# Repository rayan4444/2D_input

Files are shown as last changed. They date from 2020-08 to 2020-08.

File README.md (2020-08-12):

# 2D Input on any surface

Eagle files Repository for 2D input project

## Modular version
Based on ESP32 to test different hardware configurations. One PCB design that can be snapped to separate core and peripheral modules. Test code available.

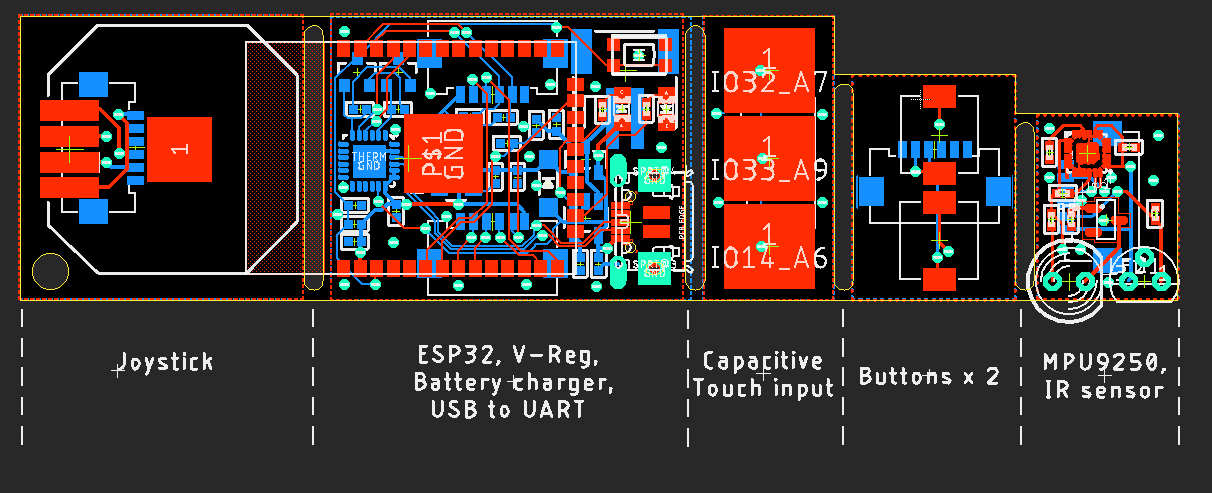
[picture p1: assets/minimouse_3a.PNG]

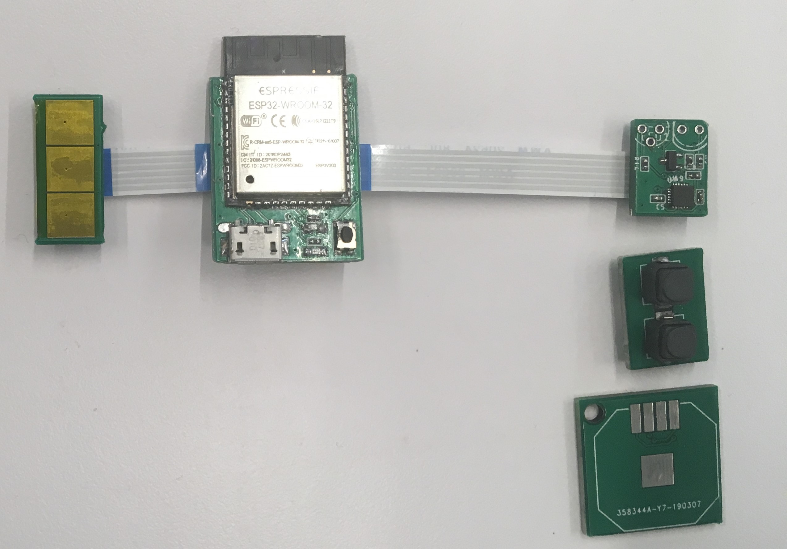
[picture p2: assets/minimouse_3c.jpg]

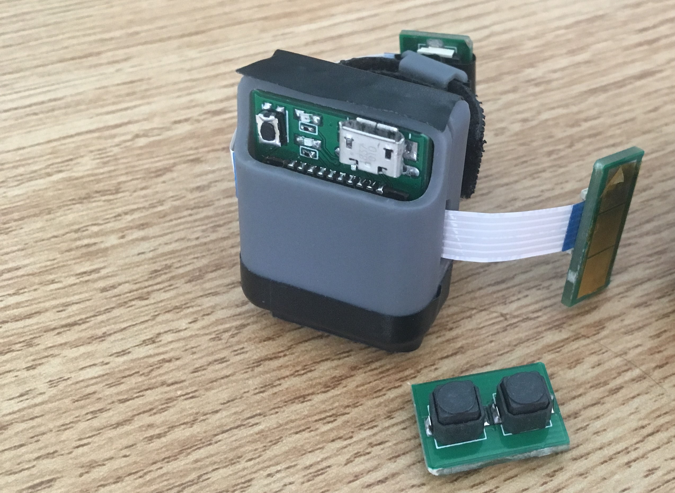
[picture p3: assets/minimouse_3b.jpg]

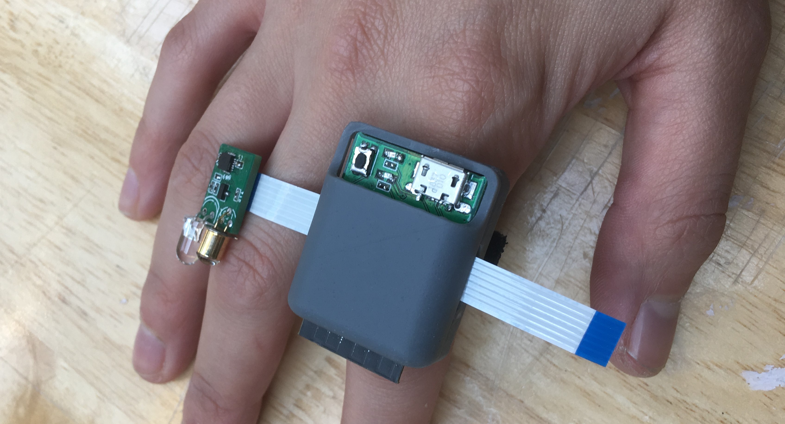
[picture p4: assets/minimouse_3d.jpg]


## Downsized version
Based on NRF52 as a first step to real manufacturing size. Firmware not available

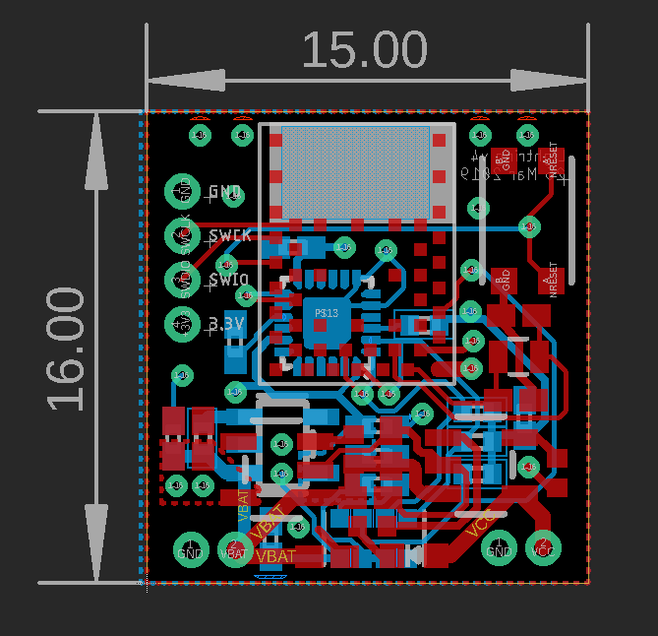
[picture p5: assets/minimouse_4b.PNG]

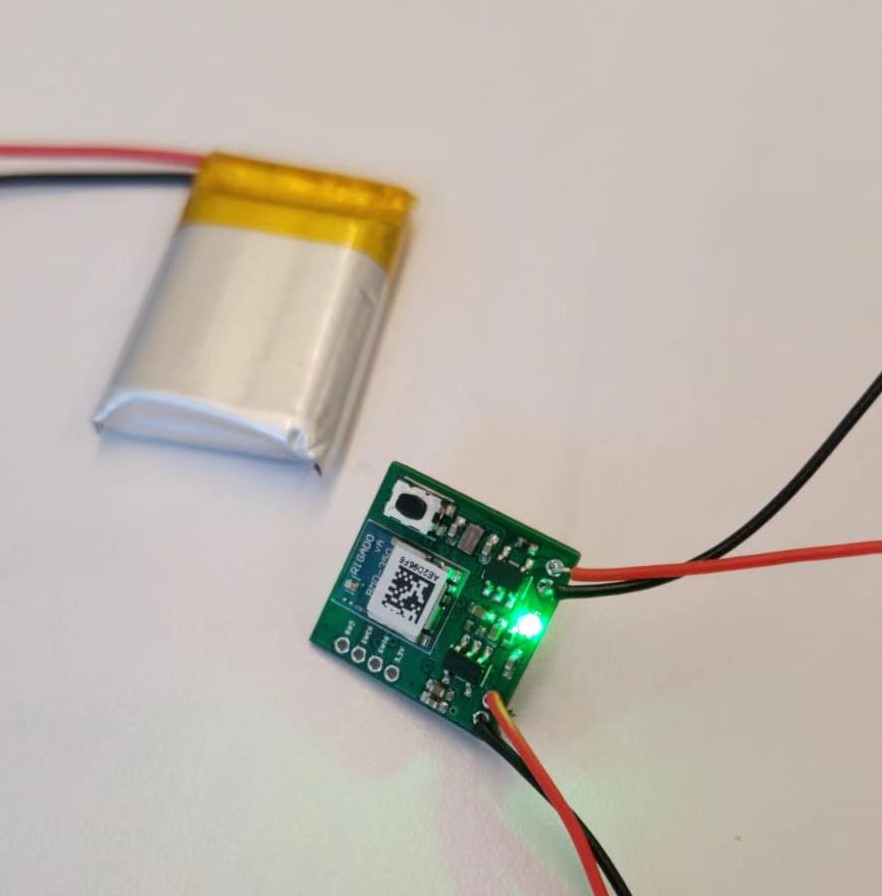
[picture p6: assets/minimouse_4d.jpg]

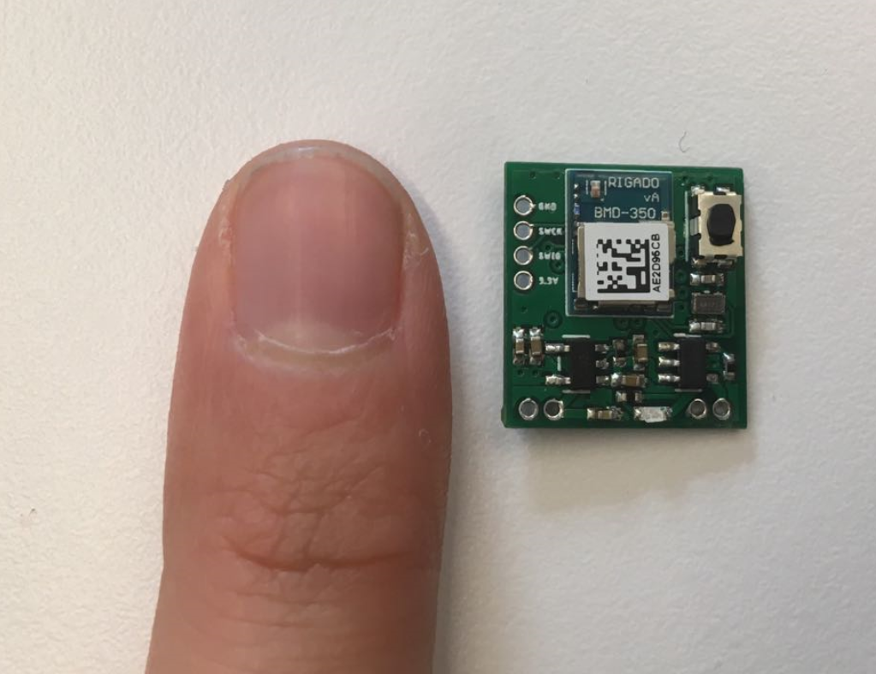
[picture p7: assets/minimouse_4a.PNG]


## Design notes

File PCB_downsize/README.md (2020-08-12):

# 2D Input on any surface - Downsized PCB

## Features
* NRF52 (BMD350 module)
* SWD Programming & debugging port
* 1S Li-Po charger
* 3.3V & 1.8V LDO
* MPU9250 IMU
* VCNL36687S Proximity sensor

## Hardware connections

|Signal|Pin|Note|
|:---:|:---:|:---:|
|RESET|21||
|INT_IMU|17||
|INT_IR|30||
|SDA|6||
|SCL|8||

## Debugging notes
* VCNL36687S soldered at 90 deg: one side pins soldered, other side using rework wire
* Add connector to external button in next version

## Programming
* Didn't get permission to share firmware
* [NRF52 dev with visual studio code](https://github.com/rayan4444/vs_code_setup_tutorials/tree/master/NRF52)

## Datasheets
* [BMD350](https://www.u-blox.com/sites/default/files/BMD-350_DataSheet_%28UBX-19033354%29.pdf)
* [MPU9250](https://invensense.tdk.com/wp-content/uploads/2015/02/PS-MPU-9250A-01-v1.1.pdf)
* [VCNL36687S](https://www.vishay.com/docs/84907/vcnl36687s.pdf)

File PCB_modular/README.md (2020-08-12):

# 2D Input on any surface - Modular PCB

## Features
Modular version - Core
* ESP32-WROOM32 Module
* CP2104 USB-UART bridge
* 1S Li-Po charger
* 3.3V LDO
* 2x FPC breakout connectors

Modular version - Peripherals
* MPU9250 IMU
* Custom narrow angle IR sensor ( & )
* 2x buttons
* Capacitive touch sensor board (3 positions)
* Joystick

## Hardware connections

|Signal| Arduino Pin|Note|
|:---:|:---:|:---:|
|RXD0|RXD0|Programming|
|TXD0|TXD0|Programming|
|IMU_SDA|23|
|IMU_SCL|22|
|BUTTON 1 or CAP_TOUCH_1|14, A6||
|BUTTON 2|15||
|CAP_TOUCH_2 or JOY_X|33, A9||
|CAP_TOUCH_3 or JOY_Y|32, A7||
|LED|13||
|IR_LED|12||
|IR_SENSOR_OUT|34, A2|Analog|

## Programming
Follow normal Arduino for ESP32 instructions. Select "Adafruit feather" as Board in Arduino IDE to program.

## Errata
* MPU9250 is discontinued - don't use it for any new designs
* Problem: cannot connect to the MCU to flash it.   
    * Solution: Missing trace on GPIO0 line that connects to the auto-reset circuit. Used a rework wire as a temporary fix.

## References & tutorials
* [MPU4920 datasheet]()
* [Capacitive touch sensor design guide]()

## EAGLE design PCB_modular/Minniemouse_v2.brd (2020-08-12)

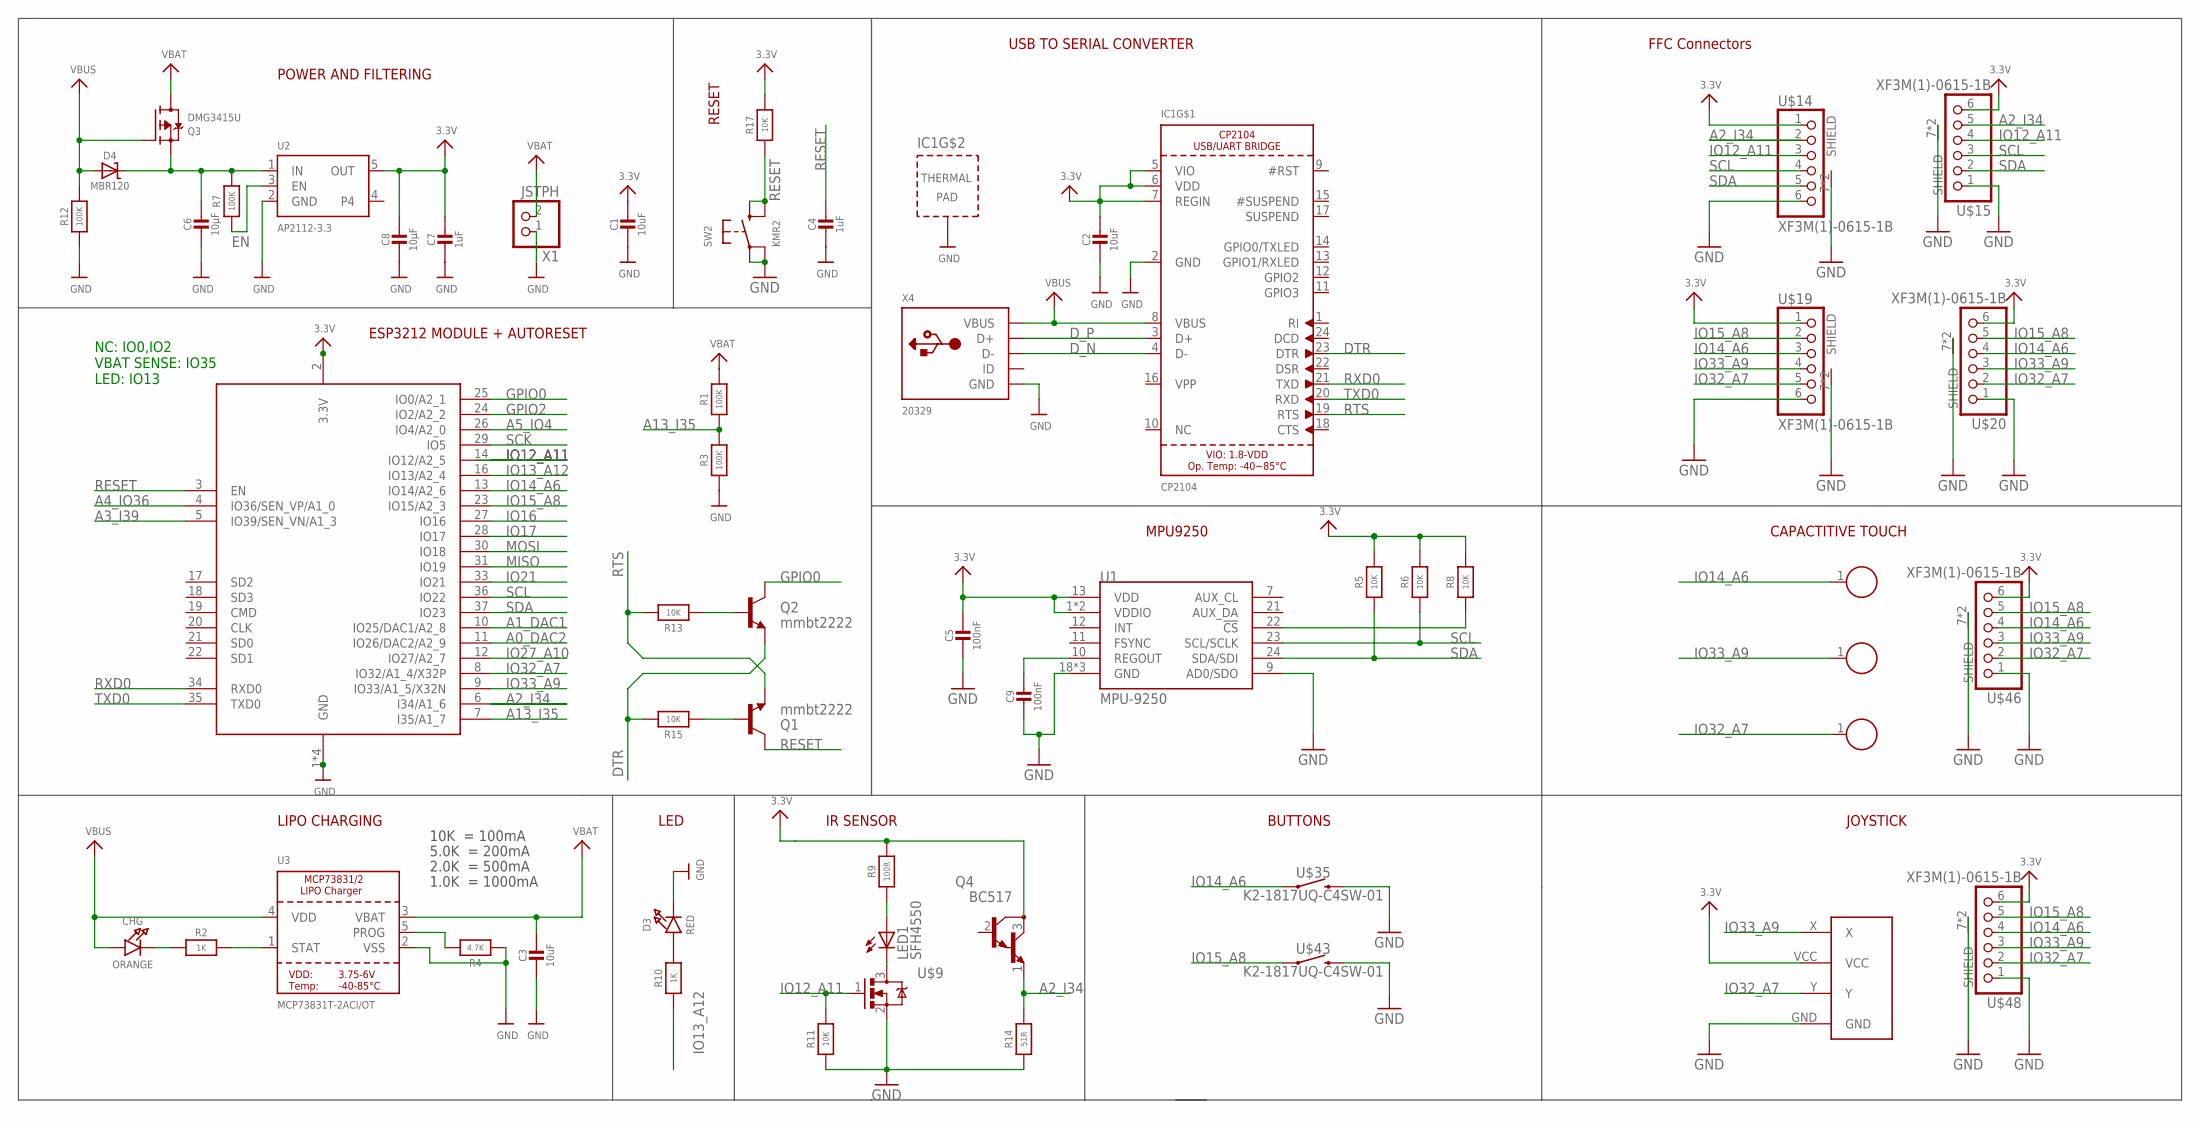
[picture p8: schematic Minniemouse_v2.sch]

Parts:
C1, C2, C3: 10uF; _0402
C4, C7: 1uF; _0402
C5, C9: 100nF; _0402
C6, C8: 10µF; _0402
CHG: ORANGE; CHIPLED_0805_NOOUTLINE
D3: RED; CHIPLED_0805_NOOUTLINE
D4: MBR120; SOD-123
IC1: CP2104; QFN24_4MM_SMSC
LED1: SFH4550; LED_LED5MM
P1, P2, P3: CAPTOUCH_PAD; CAPTOUCH_6.5X7
Q1, Q2: mmbt2222; SOT23-3
Q3: DMG3415U; SOT23-R
Q4: BC517; TO92
R1, R3, R7, R12: 100K; _0402
R2, R10: 1K; _0402
R4: 4.7K; _0402
R5, R6, R8, R11, R13, R15, R17: 10K; _0402
R9: 100R; _0402
R14: 51R; _0402
SW2: KMR2; BTN_KMR2_4.6X2.8
U1: MPU-9250; QFN24_PAD
U2: AP2112-3.3; SOT23-5
U3: MCP73831T-2ACI/OT; SOT23-5
U$9: DMN6140L; SOT91P240X110-3N
U$14, U$15, U$19, U$20, U$46, U$48: XF3M(1)-0615-1B
U$35, U$43: K2-1817UQ-C4SW-01
U$49: JOYSTICK
X1: JSTPH; JSTPH2
X2: ESP32_WROOM32_SKINNY; WROOM32_SKINNY
X4: 20329; 4UCONN_20329_V2

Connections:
3.3V: C1.1, C2.1, C5.1, C7.1, C8.1, IC1.5 (VIO), IC1.6 (VDD), IC1.7 (REGIN), Q4.3 (C), R5.2, R6.2, R8.2, R9.2, R17.2, U1.1 (VDDIO), U1.8 (VDDIO), U1.13 (VDD), U2.5 (OUT), U$14.1, U$15.6, U$19.1, U$20.6, U$46.6, U$48.6, U$49.VCC, X2.2 (3.3V)
!CS: R8.1, U1.22 (!CS)
A0_DAC2: X2.11 (IO26/DAC2/A2_9)
A1_DAC1: X2.10 (IO25/DAC1/A2_8)
A2_I34: Q4.1 (E), R14.2, U$14.2, U$15.5, X2.6 (I34/A1_6)
A3_I39: X2.5 (IO39/SEN_VN/A1_3)
A4_IO36: X2.4 (IO36/SEN_VP/A1_0)
A5_IO4: X2.26 (IO4/A2_0)
A13_I35: R1.1, R3.2, X2.7 (I35/A1_7)
DTR: IC1.23 (DTR), Q2.2 (E), R15.2
D_N: IC1.4 (D-), X4.D-
D_P: IC1.3 (D+), X4.D+
EN: R7.1, U2.3 (EN)
GND: C1.2, C2.2, C3.2, C4.2, C5.2, C6.2, C7.2, C8.2, C9.2, D3.C, IC1.2 (GND), IC1.THERM (TP), R3.1, R4.1, R11.1, R12.1, R14.1, SW2.A, SW2.A' (P1), U1.9 (AD0/SDO), U1.18 (GND), U1.20 (GND), U1.CENTER (GND), U2.2 (GND), U3.2 (VSS), U$9.2, U$14.6, U$14.7 (SHIELD), U$14.8 (SHIELD), U$15.1, U$15.7 (SHIELD), U$15.8 (SHIELD), U$19.6, U$19.7 (SHIELD), U$19.8 (SHIELD), U$20.1, U$20.7 (SHIELD), U$20.8 (SHIELD), U$35.P$2 (2), U$43.P$2 (2), U$46.1, U$46.7 (SHIELD), U$46.8 (SHIELD), U$48.1, U$48.7 (SHIELD), U$48.8 (SHIELD), U$49.GND, X1.1, X2.1 (GND), X2.15 (GND), X2.38 (GND), X2.P$1 (GND), X4.BASE@1 (GND), X4.BASE@2 (GND), X4.GND, X4.SPRT@1 (GND), X4.SPRT@2 (GND), X4.SPRT@3 (GND), X4.SPRT@4 (GND)
GPIO0: Q2.3 (C), X2.25 (IO0/A2_1)
GPIO2: X2.24 (IO2/A2_2)
IO12_A11: R11.2, U$9.1, U$14.3, U$15.4, X2.14 (IO12/A2_5)
IO13_A12: R10.1, X2.16 (IO13/A2_4)
IO14_A6: P1.1, U$19.3, U$20.4, U$35.P$1 (1), U$46.4, U$48.4, X2.13 (IO14/A2_6)
IO15_A8: U$19.2, U$20.5, U$43.P$1 (1), U$46.5, U$48.5, X2.23 (IO15/A2_3)
IO16: X2.27 (IO16)
IO17: X2.28 (IO17)
IO21: X2.33 (IO21)
IO27_A10: X2.12 (IO27/A2_7)
IO32_A7: P3.1, U$19.5, U$20.2, U$46.2, U$48.2, U$49.Y, X2.8 (IO32/A1_4/X32P)
IO33_A9: P2.1, U$19.4, U$20.3, U$46.3, U$48.3, U$49.X, X2.9 (IO33/A1_5/X32N)
MISO: X2.31 (IO19)
MOSI: X2.30 (IO18)
unnamed: CHG.C, R2.1
unnamed: R2.2, U3.1 (STAT)
unnamed: R4.2, U3.5 (PROG)
unnamed: D3.A, R10.2
unnamed: C6.1, D4.C, Q3.2 (S), R7.2, U2.1 (IN)
unnamed: Q2.1 (B), R13.1
unnamed: LED1.A, R9.1
unnamed: LED1.K (C), U$9.3
unnamed: Q1.1 (B), R15.1
REGOUT: C9.1, U1.10 (REGOUT)
RESET: C4.1, Q1.3 (C), R17.1, SW2.B (S), SW2.B' (S1), X2.3 (EN)
RTS: IC1.19 (RTS), Q1.2 (E), R13.2
RXD0: IC1.21 (TXD), X2.34 (RXD0)
SCK: X2.29 (IO5)
SCL: R6.1, U1.23 (SCL/SCLK), U$14.4, U$15.3, X2.36 (IO22)
SDA: R5.1, U1.24 (SDA/SDI), U$14.5, U$15.2, X2.37 (IO23)
TXD0: IC1.20 (RXD), X2.35 (TXD0)
VBAT: C3.1, Q3.3 (D), R1.2, U3.3 (VBAT), X1.2
VBUS: CHG.A, D4.A, IC1.8 (VBUS), Q3.1 (G), R12.2, U3.4 (VDD), X4.VBUS

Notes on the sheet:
POWER AND FILTERING
RESET
10K = 100mA
5.0K = 200mA
2.0K = 500mA
1.0K = 1000mA
USB TO SERIAL CONVERTER
LIPO CHARGING
LED
ESP3212 MODULE + AUTORESET
NC: IO0,IO2 VBAT SENSE: IO35 LED: IO13
MPU9250
IR SENSOR
BUTTONS
FFC Connectors
CAPACTITIVE TOUCH
JOYSTICK

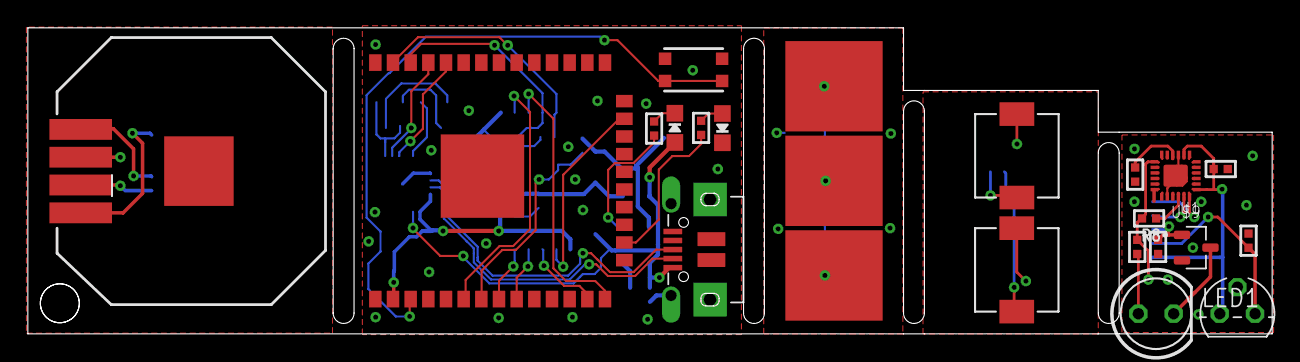
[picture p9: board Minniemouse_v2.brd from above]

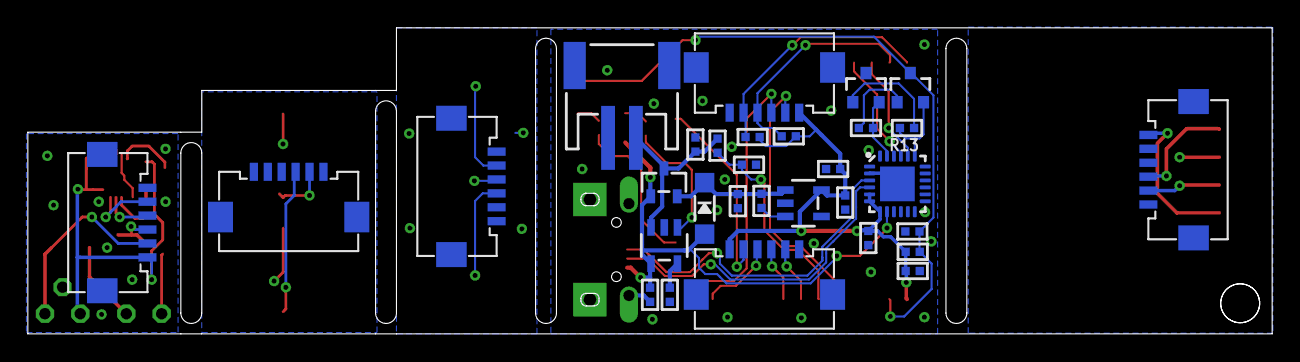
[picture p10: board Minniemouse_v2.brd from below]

Board: 2 copper layers, 89.4 x 22.0 mm, 54 parts (31 on the bottom side), 34 nets.

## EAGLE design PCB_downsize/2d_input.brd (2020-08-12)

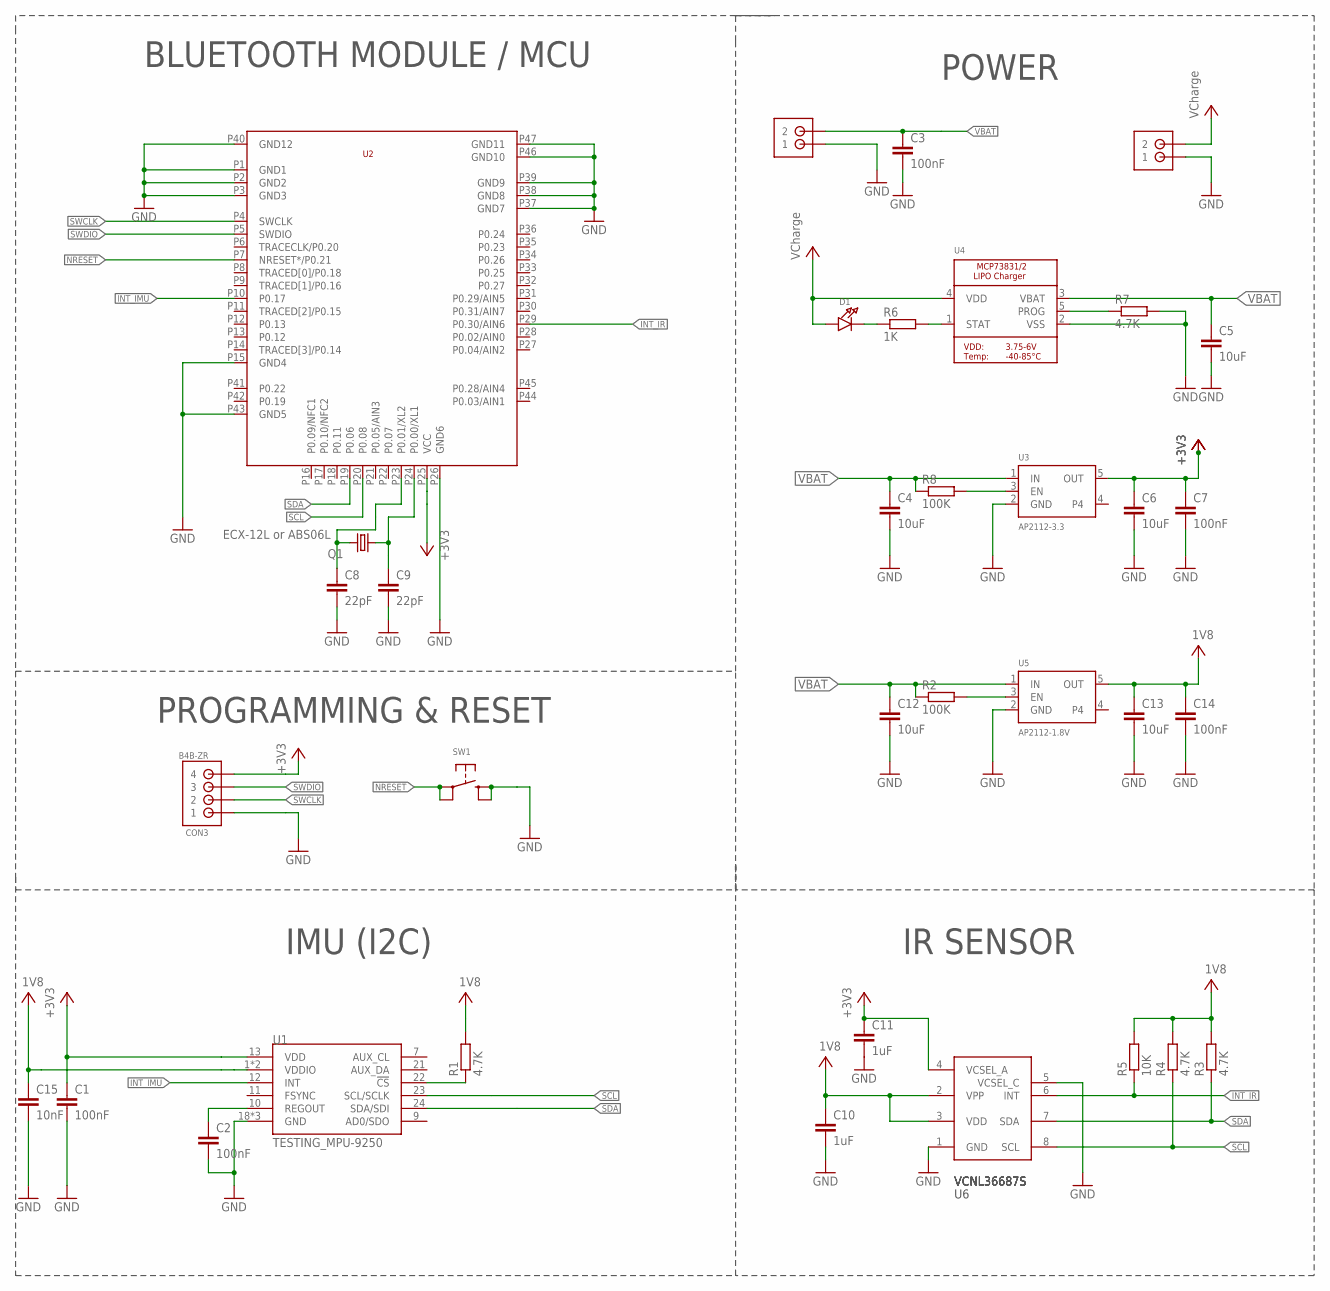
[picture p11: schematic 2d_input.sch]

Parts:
C1, C2, C3, C7, C14: 100nF; C0402K
C4, C5, C6, C12, C13: 10uF; C0402K
C8, C9: 22pF; C0402K
C10, C11: 1uF; C0402K
C15: 10nF; C0402K
CON1, CON2: B2B-ZR
CON3: B4B-ZR
D1: MICROBUILDER_LED0603_NOOUTLINE; MICROBUILDER_CHIPLED_0603_NOOUTLINE
Q1: ECX-12L or ABS06L; 2.0X1.2
R1, R3, R4, R7: 4.7K; R0402
R2, R8: 100K; R0402
R5: 10K; R0402
R6: 1K; R0402
SW1: MICROBUILDER_SWITCH_TACT_SMT4.6X2.8; MICROBUILDER_BTN_KMR2_4.6X2.8
U1: TESTING_MPU-9250; TESTING_QFN24_PAD
U2: BMD-350
U3: AP2112-3.3; MICROBUILDER_SOT23-5
U4: MICROBUILDER_MCP73831/2; MICROBUILDER_SOT23-5
U5: AP2112-1.8V; MICROBUILDER_SOT23-5
U6: VCNL36687S

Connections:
+3V3: C1.1, C6.1, C7.1, C11.1, CON3.4, U1.13 (VDD), U2.P25 (VCC), U3.5 (OUT), U6.4 (VCSEL_A)
GND: C1.2, C2.2, C3.2, C4.2, C5.2, C6.2, C7.2, C8.2, C9.2, C10.2, C11.2, C12.2, C13.2, C14.2, C15.2, CON1.1, CON2.1, CON3.1, R7.2, SW1.B (S), SW1.B' (S1), U1.18 (GND), U1.20 (GND), U1.CENTER (GND), U2.P1 (GND1), U2.P2 (GND2), U2.P3 (GND3), U2.P15 (GND4), U2.P26 (GND6), U2.P37 (GND7), U2.P38 (GND8), U2.P39 (GND9), U2.P40 (GND12), U2.P43 (GND5), U2.P46 (GND10), U2.P47 (GND11), U3.2 (GND), U4.2 (VSS), U5.2 (GND), U6.1 (GND), U6.5 (VCSEL_C)
INT_IMU: U1.12 (INT), U2.P10 (P0.17)
INT_IR: R5.1, U2.P29 (P0.30/AIN6), U6.6 (INT)
unnamed: C2.1, U1.10 (REGOUT)
unnamed: R7.1, U4.5 (PROG)
unnamed: C9.1, Q1.1, U2.P24 (P0.00/XL1)
unnamed: R1.1, U1.22 (!CS)
unnamed: R6.2, U4.1 (STAT)
unnamed: D1.C, R6.1
unnamed: R8.2, U3.3 (EN)
unnamed: R2.2, U5.3 (EN)
unnamed: C8.1, Q1.2, U2.P23 (P0.01/XL2)
NRESET: SW1.A, SW1.A' (P1), U2.P7 (NRESET*/P0.21)
SCL: R4.1, U1.23 (SCL/SCLK), U2.P20 (P0.08), U6.8 (SCL)
SDA: R3.1, U1.24 (SDA/SDI), U2.P19 (P0.06), U6.7 (SDA)
SWCLK: CON3.2, U2.P4 (SWCLK)
SWDIO: CON3.3, U2.P5 (SWDIO)
V+: C10.1, C13.1, C14.1, C15.1, R1.2, R3.2, R4.2, R5.2, U1.1 (VDDIO), U1.8 (VDDIO), U5.5 (OUT), U6.2 (VPP), U6.3 (VDD)
VBAT: C3.1, C4.1, C5.1, C12.1, CON1.2, R2.1, R8.1, U3.1 (IN), U4.3 (VBAT), U5.1 (IN)
VCC: CON2.2, D1.A, U4.4 (VDD)

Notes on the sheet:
BLUETOOTH MODULE / MCU
IMU (I2C)
IR SENSOR
POWER
PROGRAMMING & RESET
VCNL36687S

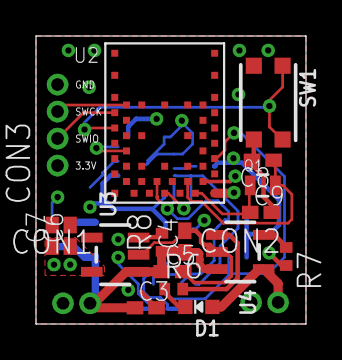
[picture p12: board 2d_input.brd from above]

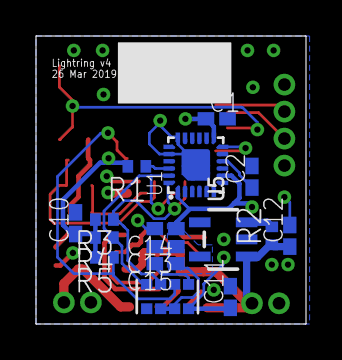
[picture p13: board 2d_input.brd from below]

Board: 4 copper layers, 15.0 x 16.0 mm, 35 parts (16 on the bottom side), 21 nets.

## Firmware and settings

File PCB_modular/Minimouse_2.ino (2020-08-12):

// #define USING_CAPTOUCH
#define USING_BUTTONS

//#define Y_ABSOLUTE
#define Y_RELATIVE

#define DEBUG

#include <BLEDevice.h>
#include <BLEUtils.h>
#include <BLEServer.h>
#include "BLE2902.h"
#include "BLEHIDDevice.h"
#include "HIDTypes.h"
#include "HIDKeyboardTypes.h"

// CHANGABLE #DEFINES !!!!!!!!!!!!!!!!!!!!!!!!!!!!!!!!!!!!!!!!!!!!!!
#define X_BOOST 2

// XY low pass filters.  Smaller number is faster response
#define LPF_INPUT 1
#define LPF_ZERO 4096

// Main loop delay, smaller is faster motion
#define DELAY 20

// UNCHANGABLE #DEFINES !!!!!!!!!!!!!!!!!!!!!!!!!!!!!!!!!!!!!!!!!!!!
// Fixed point quotient
#define QUOTIENT_MAX 4096

const int led_pin = 13;
const int battery_adc = A13; /*half voltage*/
// ADC 1 pins are: A2, A3, A4, A12 (Red LED), A9, A7

#include "mpu9250.hpp"
MPU9250 mpu = MPU9250();
//int16_t min_ir = 32767;
//int16_t max_ir = -32767;
const int ir_adc = A2;
const int irled_pin = 12;

#ifdef USING_BUTTONS
  const int button1_pin = 14;
  const int button2_pin = 15;
#endif

/*Touch Sensor Pin Layout
   T0 = GPIO4
   T1 = GPIO0
   T2 = GPIO2
   T3 = GPIO15
   T4 = GPIO13
   T5 = GPIO12
   T6 = GPIO14 // connected
   T7 = GPIO27
   T8 = GPIO33 //conected
   T9 = GPIO32 // connected
   functions: touchRead
   touchAttachInterrupt(T9, gotTouch3, threshold);
   threshold was nice at 60 with kapton tape, maybe too sensitive
   */

#ifdef USING_CAPTOUCH
  const int pad1_pin = T8;
  const int pad2_pin = T9;
  const int pad3_pin = T6;
#endif

bool connected = false;
BLEHIDDevice* hid;
BLECharacteristic* input;
BLECharacteristic* output;

#ifdef Y_RELATIVE
const uint8_t kMouseHidDescriptor[] = {
  0x05, 0x01,                         // USAGE_PAGE (Generic Desktop)     0
  0x09, 0x02,                         // USAGE (Mouse)                    2
  0xa1, 0x01,                         // COLLECTION (Application)         4
  0x85, 0x01,                         //   REPORT_ID (Mouse)              6
  0x09, 0x01,                         //   USAGE (Pointer)                8
  0xa1, 0x00,                         //   COLLECTION (Physical)          10
  0x05, 0x09,                         //     USAGE_PAGE (Button)          12
  0x19, 0x01,                         //     USAGE_MINIMUM (Button 1)     14
  0x29, 0x03,                         //     USAGE_MAXIMUM (Button 3)     16
  0x15, 0x00,                         //     LOGICAL_MINIMUM (0)          18
  0x25, 0x01,                         //     LOGICAL_MAXIMUM (1)          20
  0x75, 0x01,                         //     REPORT_SIZE (1)              22
  0x95, 0x03,                         //     REPORT_COUNT (3)             24
  0x81, 0x02,                         //     INPUT (Data,Var,Abs)         26
  0x95, 0x05,                         //     REPORT_COUNT (5)             28
  0x81, 0x03,                         //     INPUT (Cnst,Var,Abs)         30
  0x05, 0x01,                         //     USAGE_PAGE (Generic Desktop) 32
  0x09, 0x30,                         //     USAGE (X)                    34
  0x09, 0x31,                         //     USAGE (Y)                    36
  0x15, 0x81,                         //     LOGICAL_MINIMUM (-127)       38
  0x25, 0x7f,                         //     LOGICAL_MAXIMUM (127)        40
  0x75, 0x08,                         //     REPORT_SIZE (8)              42
  0x95, 0x02,                         //     REPORT_COUNT (2)             44
  0x81, 0x06,                         //     INPUT (Data,Var,Rel)         46
  0xc0,                               //   END_COLLECTION                 48
  0xc0                                // END_COLLECTION                   49/50
};
 
typedef struct
{
  uint8_t  ButtonOne  : 1;  // bool
  uint8_t  ButtonTwo  : 1;  // bool
  uint8_t  ButtonThree: 1;  // bool
  uint8_t  X;               // int8_t
  uint8_t  Y;               // int8_t
} InputMouse_t;
#endif // Y_RELATIVE

#ifdef Y_ABSOLUTE
const uint8_t kMouseHidDescriptor[] = {
  0x05, 0x01,                         // USAGE_PAGE (Generic Desktop)     0
  0x09, 0x02,                         // USAGE (Mouse)                    2
  0xa1, 0x01,                         // COLLECTION (Application)         4
  0x85, 0x01,                         //   REPORT_ID (Mouse)              6
  0x09, 0x01,                         //   USAGE (Pointer)                8
  0xa1, 0x00,                         //   COLLECTION (Physical)          10
  
  0x05, 0x09,                         //     USAGE_PAGE (Button)          12
  0x19, 0x01,                         //     USAGE_MINIMUM (Button 1)     14
  0x29, 0x03,                         //     USAGE_MAXIMUM (Button 3)     16
  0x15, 0x00,                         //     LOGICAL_MINIMUM (0)          18
  0x25, 0x01,                         //     LOGICAL_MAXIMUM (1)          20
  0x75, 0x01,                         //     REPORT_SIZE (1)              22
  0x95, 0x03,                         //     REPORT_COUNT (3)             24
  0x81, 0x02,                         //     INPUT (Data,Var,Abs)         26
  0x95, 0x05,                         //     REPORT_COUNT (5)             28
  0x81, 0x03,                         //     INPUT (Cnst,Var,Abs)         30

  0x05, 0x01,                         //     USAGE_PAGE (Generic Desktop) 32
  0x09, 0x30,                         //     USAGE (X)                    34
  0x15, 0x81,                         //     LOGICAL_MINIMUM (-127)       36
  0x25, 0x7f,                         //     LOGICAL_MAXIMUM (127)        38
  0x75, 0x08,                         //     REPORT_SIZE (8)              40
  0x95, 0x01,                         //     REPORT_COUNT (1)             42
  0x81, 0x02,                         //     INPUT (Data,Var,Abs)         44

  0x05, 0x01,                         //     USAGE_PAGE (Generic Desktop) 46
  0x09, 0x31,                         //     USAGE (Y)                    48
  0x16, 0x01, 0xf8,                   //     LOGICAL_MINIMUM (-2047)      50
  0x26, 0xff, 0x07,                   //     LOGICAL_MAXIMUM (2047)       53
  0x75, 0x10,                         //     REPORT_SIZE (16)             56
  0x95, 0x01,                         //     REPORT_COUNT (1)             58
  0x81, 0x02,                         //     INPUT (Data,Var,Abs)         60

  0xc0,                               //   END_COLLECTION                 62
  0xc0                                // END_COLLECTION                   63/64
};
 
typedef struct
{
  uint8_t  ButtonOne  : 1;  // bool
  uint8_t  ButtonTwo  : 1;  // bool
  uint8_t  ButtonThree: 1;  // bool
  int8_t  X;                // int8_t
  int16_t Y;                // int16_t
} InputMouse_t;
#endif // Y_ABSOLUTE

class MyCallbacks : public BLEServerCallbacks {
  void onConnect(BLEServer* pServer){
    connected = true;
    BLE2902* desc = (BLE2902*)input->getDescriptorByUUID(BLEUUID((uint16_t)0x2902));
    desc->setNotifications(true);
  }

  void onDisconnect(BLEServer* pServer){
    connected = false;
    BLE2902* desc = (BLE2902*)input->getDescriptorByUUID(BLEUUID((uint16_t)0x2902));
    desc->setNotifications(false);
  }
};

void taskServer(void*){
  BLEDevice::init("MiniMouse1");
  BLEServer *pServer = BLEDevice::createServer();
  pServer->setCallbacks(new MyCallbacks());

  hid = new BLEHIDDevice(pServer);
  input = hid->inputReport(1); // <-- input REPORTID from report map
  output = hid->outputReport(1); // <-- output REPORTID from report map

  std::string name = "MidKnights";
  hid->manufacturer()->setValue(name);

  hid->pnp(0x02, 0xe502, 0xa111, 0x0210);
  hid->hidInfo(0x00,0x02);

  hid->reportMap((uint8_t*)kMouseHidDescriptor, sizeof(kMouseHidDescriptor));
  hid->startServices();


  BLESecurity *pSecurity = new BLESecurity();
//  pSecurity->setKeySize();
  pSecurity->setAuthenticationMode(ESP_LE_AUTH_BOND);


  BLEAdvertising *pAdvertising = pServer->getAdvertising();
  pAdvertising->setAppearance(HID_MOUSE);
  pAdvertising->addServiceUUID(hid->hidService()->getUUID());
  pAdvertising->start();
  hid->setBatteryLevel(7);

  delay(portMAX_DELAY);
}

int16_t SampleIR()
{
  int16_t val_on, val_off;
  // Turn on IR LED
  digitalWrite(irled_pin, HIGH);
  delay(1);
  // sample
  val_on = analogRead(ir_adc);
  // Turn off IR LED
  digitalWrite(irled_pin, LOW); // PFET turns off when gate pulled high
  delay(1);
  // sample baseline
  val_off = analogRead(ir_adc);
  return val_on-val_off;
}

void setup() {
  #ifdef DEBUG
  Serial.begin(115200);
  #endif

  pinMode(led_pin, OUTPUT);

  #ifdef USING_BUTTONS
  pinMode(button1_pin, INPUT_PULLUP);
  pinMode(button2_pin, INPUT_PULLUP);
  #endif

  #ifdef DEBUG
  Serial.println("Starting MPU");
  #endif
  mpu.begin();
  mpu.set_gyro_range(RANGE_GYRO_250); // slowest, since fingers are slow
  pinMode(irled_pin, OUTPUT);
  digitalWrite(irled_pin, LOW); // PFET turns on when gate pulled low

  #ifdef DEBUG
  Serial.println("Starting BLE");
  #endif
  xTaskCreate(taskServer, "server", 20000, NULL, 5, NULL);

  #ifdef DEBUG
  Serial.println("Running loop");
  #endif
}

void loop() {
  // Persistant variables
  static int32_t x_filt = 0;
  static int32_t y_filt = 0;
  static int32_t x_zero = 0;
  static int32_t y_zero = 0;
  static int8_t b1_last = 0;
  static int8_t b2_last = 0;
  static int8_t b3_last = 0;
  static int8_t b3_toggle = 0;
  static int16_t y_min = 32767;
  static int16_t y_max = -23767;
  static int8_t y_boost = 0;

  // Temporary variables
  int8_t send_report = 0;

  delay(DELAY);

  // Check battery voltage
  if ((analogRead(battery_adc)*2)<3.3){
    digitalWrite(led_pin, !digitalRead(led_pin));
  }

  // Buttons, cap buttons
  #ifdef USING_BUTTONS
  // Buttons
  int8_t b1_now = !digitalRead(button1_pin);
  int8_t b2_now = !digitalRead(button2_pin);
  int8_t b3_now = 0;
  #endif

  #ifdef USING_CAPTOUCH //pad pin 3 pin gets randomly triggered
  int8_t b1_now = touchRead(pad1_pin)<60;
  int8_t b2_now = touchRead(pad1_pin)<60;
  int8_t b3_now = touchRead(pad1_pin)<30;
  #endif
  
  int8_t b1 = b1_now;
  int8_t b2 = b2_now;
  int8_t b3 = b3_now;
  if(b1_now != b1_last)
  {
    send_report = 1;
  }
  b1_last = b1_now;
  
  if(b2_now != b2_last)
  {
    send_report = 1;
  }
  b2_last = b2_now;

  // I can't get this to work for middle click...
  // might as well use it for something else
  if(b3_now == 1 && b3_last == 0)
  {
    send_report = 1;
    b3_toggle = !b3_toggle;
  }
  b3_last = b3_now;

  // Gyro
  mpu.get_gyro();
  int32_t x_now = (mpu.gz)>>4; // 16bit, natively int16_t, shift to 12bit
  // Limit inputs to expected values (who knows what can happen to the signals)
  x_now = constrain(x_now*X_BOOST,-2047,2047);
  // To SIQ number
  x_now = x_now*QUOTIENT_MAX; 
  // Process input through filter and zero
  // The /? is the decay to zero.  If ? is large, the decay is small.
  x_filt += (x_now - x_filt)/LPF_INPUT; 
  x_zero += (x_now - x_zero)/LPF_ZERO;
  int8_t x = constrain((x_filt - x_zero)/(QUOTIENT_MAX*16),-127,127);
  
  // IR
#ifdef Y_RELATIVE
  static int16_t last_IR = 0;
  int16_t this_IR = SampleIR();
  int32_t y_now = (this_IR - last_IR); // 12 bit, make signed
  last_IR = this_IR;
  if(this_IR < y_min)
    y_min = this_IR;
  if(this_IR > y_max)
    y_max = this_IR;

    /*
  // Limit inputs to expected values (who knows what can happen to the signals)
  int16_t y_range = constrain(y_max-y_min,1,4096);
  y_boost = 4096/y_range;
  y_now = constrain(y_now*y_boost,-2047,2047);
  // To SIQ number
  y_now = y_now*QUOTIENT_MAX;  
  // Process input through filter and zero
  // The /? is the decay to zero.  If ? is large, the decay is small.
  y_filt += (y_now - y_filt)/LPF_INPUT; 
  y_zero += (y_now - y_zero)/LPF_ZERO;
  int8_t y = constrain((y_filt - y_zero)/(QUOTIENT_MAX*16),-127,127);
  */
  int8_t y = constrain(y_now,-127,127);
#endif // Y_RELATIVE

#ifdef Y_ABSOLUTE
  int32_t y_now = SampleIR();
  if(y_now < y_min)
    y_min = y_now;
  if(y_now > y_max)
    y_max = y_now;
    
  // To SIQ number
  y_now = y_now*QUOTIENT_MAX;  
  // Process input through filter and zero
  // The /? is the decay to zero.  If ? is large, the decay is small.
  y_filt += (y_now - y_filt)/LPF_INPUT; 
  int16_t y = 0;
  if(y_max - y_min > 0)
    y = constrain((y_filt - y_min*QUOTIENT_MAX)/(y_max - y_min),0,QUOTIENT_MAX-1)-2047;
#endif // Y_ABSOLUTE

  // Extra delay for slow motion
  /*int32_t additional_delay = 30*((512/SENSITIVITY_DIV) - abs(x) - abs(y))/(512/SENSITIVITY_DIV);
  if(additional_delay > 0)
    delay(additional_delay);*/
  
  if(x != 0 || y != 0)
    send_report = 1;

  if(connected && send_report){
    InputMouse_t mouse_input_now{};
    mouse_input_now.X = x;
    mouse_input_now.Y = y;
    mouse_input_now.ButtonOne = b1;
    mouse_input_now.ButtonTwo = b2;
    mouse_input_now.ButtonThree = b3;
    input->setValue((uint8_t*)&mouse_input_now,sizeof(mouse_input_now));
    input->notify();

#ifdef DEBUG
    uint8_t* output = (uint8_t*)&mouse_input_now;
    Serial.print(output[0]);
    Serial.print(", ");
    Serial.print(x);
    Serial.print(", ");
    Serial.print(y);
//    Serial.print(", ");
//    Serial.print(DELAY+additional_delay);
    Serial.println();
#endif
  }
}

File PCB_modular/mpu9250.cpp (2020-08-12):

#include "mpu9250.hpp"

uint8_t MPU9250::begin() {
  Wire.begin();
  Wire.setClock(400000L);
  
  if (__read_byte(MPU9250_ADDRESS, WHO_AM_I) != WHO_AM_I_RESP)
  {
    while(1){
      Serial.print("MPU ID is: 0x");
      Serial.print(WHO_AM_I_RESP, HEX);
      Serial.print(", but the correct should be: 0x");
      Serial.println(__read_byte(MPU9250_ADDRESS, WHO_AM_I), HEX);
      delay(1000);
    }
  }
  
  // Reset the internal registers and restores the default settings.
  __write_byte(MPU9250_ADDRESS, PWR_MGMT_1, 0b10000000);
  
  delay(100);
  
  // Activate all sensors
  __write_byte(MPU9250_ADDRESS, PWR_MGMT_2, 0x00); 


  //Mag startup
  // Activate bypass to access Magnetometer
  __write_byte(MPU9250_ADDRESS, INT_PIN_CFG, 0x02);

  // Verify ID
  if (__read_byte(AK8963_ADDRESS, WHO_AM_I_AK8963) != WHO_AM_I_RESP_MAG)
  {
    while(1){
      Serial.print("MAG ID is: 0x");
      Serial.print(WHO_AM_I_RESP_MAG, HEX);
      Serial.print(", but the correct should be: 0x");
      Serial.println(__read_byte(AK8963_ADDRESS, WHO_AM_I_AK8963), HEX);
      delay(1000);
    }
  }

  // Read factory ajustment data
  __write_byte(AK8963_ADDRESS, AK8963_CNTL, 0x00);
  delay(10);
  // Enter Fuse ROM access mode
  __write_byte(AK8963_ADDRESS, AK8963_CNTL, 0x0F); 
  delay(10);

  // Read the x-, y-, and z-axis calibration values
  __read_bytes(AK8963_ADDRESS, AK8963_ASAX, 3);

  // Return x-axis sensitivity adjustment values, etc.
  MagAdjustment[0] =  (float)(Wire.read() - 128)/256. + 1.;
  MagAdjustment[1] =  (float)(Wire.read() - 128)/256. + 1.;
  MagAdjustment[2] =  (float)(Wire.read() - 128)/256. + 1.;
  __write_byte(AK8963_ADDRESS, AK8963_CNTL, 0x00); // Power down magnetometer
  delay(10);

  // Set magnetometer data resolution and sample ODR
  __write_byte(AK8963_ADDRESS, AK8963_CNTL, 0b00010110);
  delay(10);
  
  return 0;
}

/**************************************
Accel
**************************************/

void MPU9250::get_accel()
{
  __read_bytes(MPU9250_ADDRESS, ACCEL_XOUT_H, 6);

  x = (Wire.read()<<8)|(Wire.read());
  y = (Wire.read()<<8)|(Wire.read());
  z = (Wire.read()<<8)|(Wire.read());
}

void MPU9250::get_accel_g()
{
  get_accel();

  uint8_t range = get_accel_range();
  uint16_t divider;
  if (range == RANGE_16G) divider = 2048;
  if (range == RANGE_8G) divider = 4096;
  if (range == RANGE_4G) divider = 8192;
  if (range == RANGE_2G) divider = 16384;

  x_g = (float)x / divider;
  y_g = (float)y / divider;
  z_g = (float)z / divider;
}

void MPU9250::set_accel_range(accel_range range)
{
  uint8_t reg = __read_byte(MPU9250_ADDRESS, ACCEL_CONFIG);
  __write_byte(MPU9250_ADDRESS, ACCEL_CONFIG, ((reg & 0b11100111)|(range<<3)));
}

accel_range MPU9250::get_accel_range()
{
  /* Read the data format register to preserve bits */
  return (accel_range)((__read_byte(MPU9250_ADDRESS, ACCEL_CONFIG) & 0b00011000)>>3);
}

/**************************************
Gyro
**************************************/

void  MPU9250::get_gyro()
{
  while(!(__read_byte(MPU9250_ADDRESS, INT_STATUS)&0b1));
  
  __read_bytes(MPU9250_ADDRESS, GYRO_XOUT_H, 6);
  
  gx = (Wire.read()<<8)|(Wire.read());
  gy = (Wire.read()<<8)|(Wire.read());
  gz = (Wire.read()<<8)|(Wire.read());
}

void MPU9250::get_gyro_d()
{
  get_gyro();

  uint8_t range = get_gyro_range();
  float divider;
  if (range == RANGE_GYRO_2000) divider = 16.4;
  if (range == RANGE_GYRO_1000) divider = 32.8;
  if (range == RANGE_GYRO_500) divider = 65.5;
  if (range == RANGE_GYRO_250) divider = 131.0;

  gx_d = (float)gx / divider;
  gy_d = (float)gy / divider;
  gz_d = (float)gz / divider;
}

void MPU9250::set_gyro_range(gyro_range range)
{
  uint8_t reg = __read_byte(MPU9250_ADDRESS, GYRO_CONFIG);
  __write_byte(MPU9250_ADDRESS, GYRO_CONFIG, ((reg & 0b11100111)|(range<<3)));
}

gyro_range MPU9250::get_gyro_range()
{
  return (gyro_range)((__read_byte(MPU9250_ADDRESS, ACCEL_CONFIG) & 0b00011000)>>3);
}

/**************************************
Mag
**************************************/

int MPU9250::get_mag()
{
  uint8_t temp[7];
  
  while(!(__read_byte(AK8963_ADDRESS, AK8963_ST1)&0x01));
  
  __read_bytes(AK8963_ADDRESS, AK8963_XOUT_L, 7);

  for(int i=0; i<=6; i++)
    temp[i] = Wire.read();

  if(!(temp[6] & 0x08)){
    //Data stored as little endian
    mx = (temp[0])|(temp[1]<<8);
    my = (temp[2])|(temp[3]<<8);
    mz = (temp[4])|(temp[5]<<8);
  }
  else
  {
    return 1;
  }
  return 0;
}

int MPU9250::get_mag_t()
{
  if(get_mag()){
    return 1;
  }

  uint8_t range = get_mag_scale();
  float divider;
  if (range == SCALE_14_BITS) divider = 8190.0;
  if (range == SCALE_16_BITS) divider = 32760.0;
    
  mx_t = (float)mx*4912.0*MagAdjustment[0] / divider;
  my_t = (float)my*4912.0*MagAdjustment[1] / divider;
  mz_t = (float)mz*4912.0*MagAdjustment[2] / divider;

  return 0;
}

void MPU9250::set_mag_scale(mag_scale scale)
{
  // Save mag configs
  uint8_t temp = __read_byte(AK8963_ADDRESS, AK8963_CNTL) & 0b00000110;
  // disable mag
  __write_byte(AK8963_ADDRESS, AK8963_CNTL, 0);
  delay(10);
  __write_byte(AK8963_ADDRESS, AK8963_CNTL, (scale << 4) | temp);
}

mag_scale MPU9250::get_mag_scale()
{
  return (mag_scale)((__read_byte(AK8963_ADDRESS, AK8963_CNTL)>>4)&0x01);
}

void MPU9250::set_mag_speed(mag_speed mspeed)
{
  // Save mag configs
  uint8_t temp = __read_byte(AK8963_ADDRESS, AK8963_CNTL) & 0b00010000;
  // disable mag
  __write_byte(AK8963_ADDRESS, AK8963_CNTL, 0);
  delay(10);
  if(mspeed==MAG_8_Hz)
    __write_byte(AK8963_ADDRESS, AK8963_CNTL, 0b0010| temp);
  else
    __write_byte(AK8963_ADDRESS, AK8963_CNTL, 0b0110| temp);
}

mag_speed MPU9250::get_mag_speed()
{
  uint8_t temp = __read_byte(AK8963_ADDRESS, AK8963_CNTL)&0x0F;
  if (temp==0b0010)
    return MAG_8_Hz;
  else
    return MAG_100_Hz;
}

/**************************************
Temperature
**************************************/

int16_t MPU9250::get_temp(){
  __read_bytes(MPU9250_ADDRESS, TEMP_OUT_H, 2);

  return ((Wire.read()<<8)|Wire.read());
}

/**************************************
Functions to read and write in I2C
**************************************/

void MPU9250::__write_byte(uint8_t adress, uint8_t reg, uint8_t value)
{
  Wire.beginTransmission(adress);
  Wire.write(reg);
  Wire.write(value);
  Wire.endTransmission();
}

uint8_t MPU9250::__read_byte(uint8_t adress, uint8_t reg)
{
    #if defined(__SAM3X8E__)
      // For Arduino Due bug
      Wire.requestFrom(adress, 1, reg, 1, true);
    #else
      Wire.beginTransmission(adress);
      Wire.write(reg);
      Wire.endTransmission(false);
  
      Wire.requestFrom(adress, 1);
    #endif
    
    if (!Wire.available()){
      return 0;
    }
    return Wire.read();
}
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

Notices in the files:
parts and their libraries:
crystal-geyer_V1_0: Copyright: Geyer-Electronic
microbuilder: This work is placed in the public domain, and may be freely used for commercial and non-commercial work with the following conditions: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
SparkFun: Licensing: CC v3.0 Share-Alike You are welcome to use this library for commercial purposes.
